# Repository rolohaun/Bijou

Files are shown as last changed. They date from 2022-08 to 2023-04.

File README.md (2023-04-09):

# Bijou

THE ROOK 2020 has replaced this printer!!!!!!!!!

it can be found here
https://www.printables.com/model/447255-rook-2020

Welcome to the DIY 3D Printer called Bijou!

This is a tiny 140x140 H-Bot 3D Printer for beginner builders

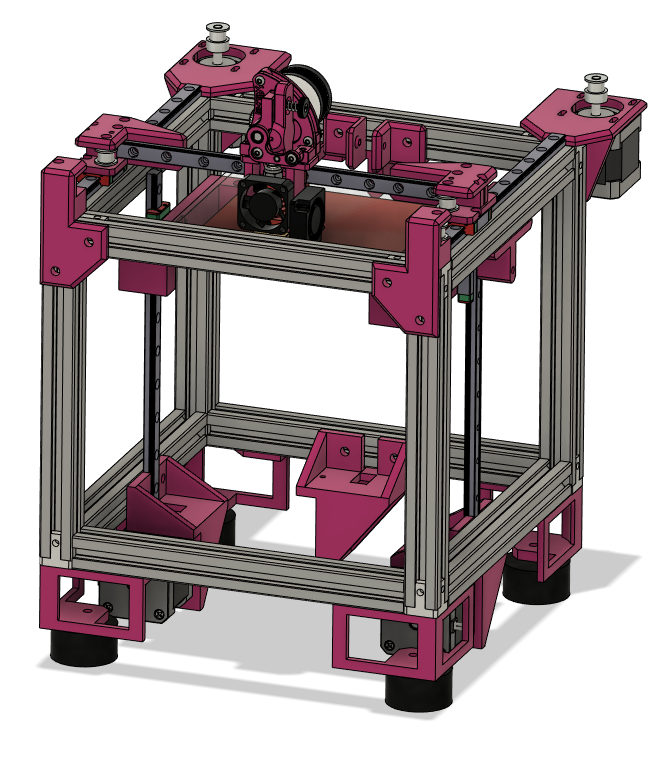
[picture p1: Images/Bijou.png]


PLEASE NOTE THIS PRINTER IS A WORK IN PROGRESS!

The goal of this printer is to make a cheap easy to build 3D printer than can be built by anyone.

Features:

- Simple 2020 Frame only 1 sizes needed, no drilling or taping
- Klicky Probe Support
- Sailfin Direct Drive Extruder Support

BOM Belted Z
https://docs.google.com/spreadsheets/d/1nYMNJQScirm3ykZU8kyfmQuEbCC1vtWDH2YyEYYs_pw/edit?usp=sharing

BOM Lead Screw Z
https://docs.google.com/spreadsheets/d/1incpOYfN3xOxOXJkBM-IeGAFThI5wXblg3JAom1FoRM/edit?usp=sharing

Assembly Videos on Youtube
https://www.youtube.com/watch?v=IN45c1hOG5U&list=PLypdl9fsWkKeVCWAPe8gXl5UOk-Ysh8ol

Support me on Patreon
https://www.patreon.com/rolohaun

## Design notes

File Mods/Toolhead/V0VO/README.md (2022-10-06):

the original V0 toolhead mod V0VO was made by Mamsih I just edited the dragon mount for Bijou. All credit goes to Mamsih for the original
https://github.com/Mamsih/VOV0-toolhead-voron-Zero

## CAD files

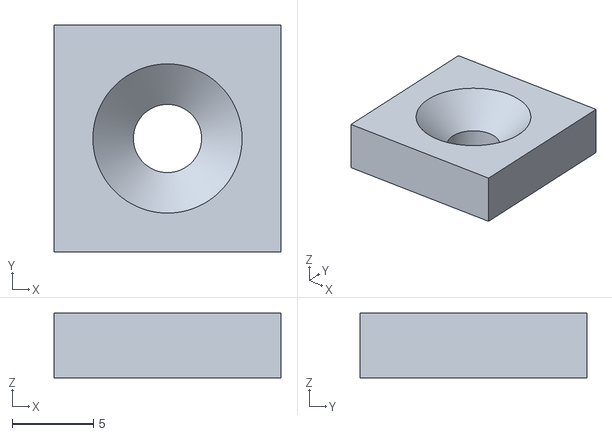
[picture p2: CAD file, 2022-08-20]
Bed/Bed_Pad.stl
14.0 x 14.0 x 4.00

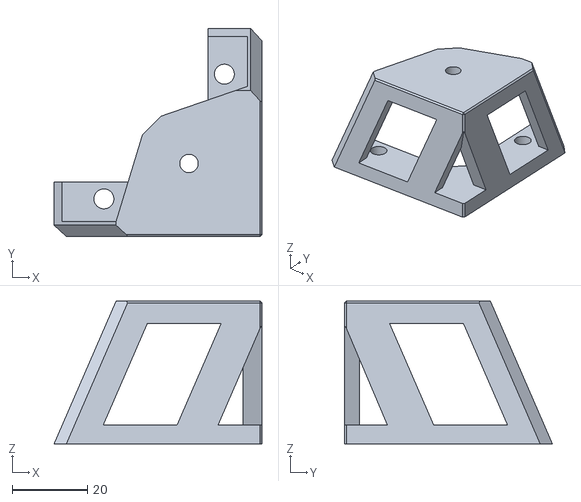
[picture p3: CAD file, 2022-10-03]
Frame + Motor Mounts/Foot_Mount.stl
55.3 x 55.3 x 38.0

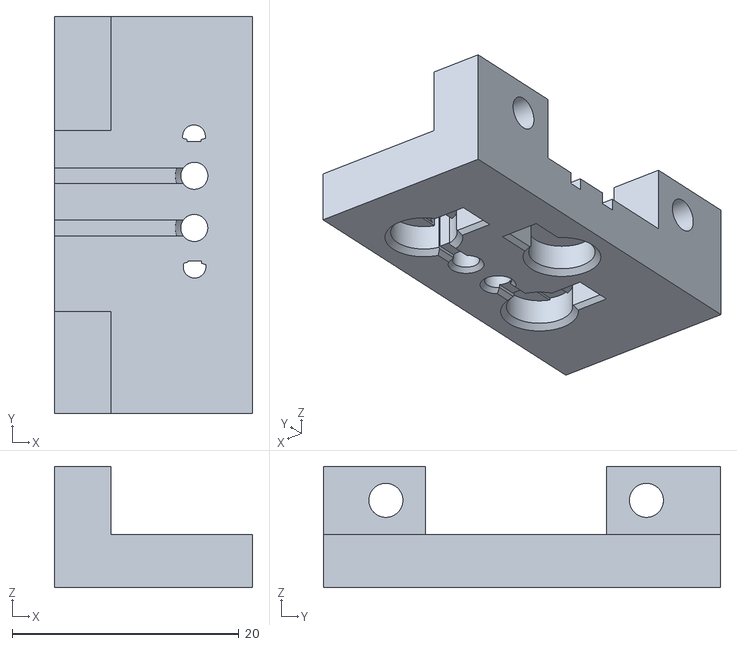
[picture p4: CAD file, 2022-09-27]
Klicky/Bijou_Probe_Mount.stl
17.5 x 35.0 x 10.7

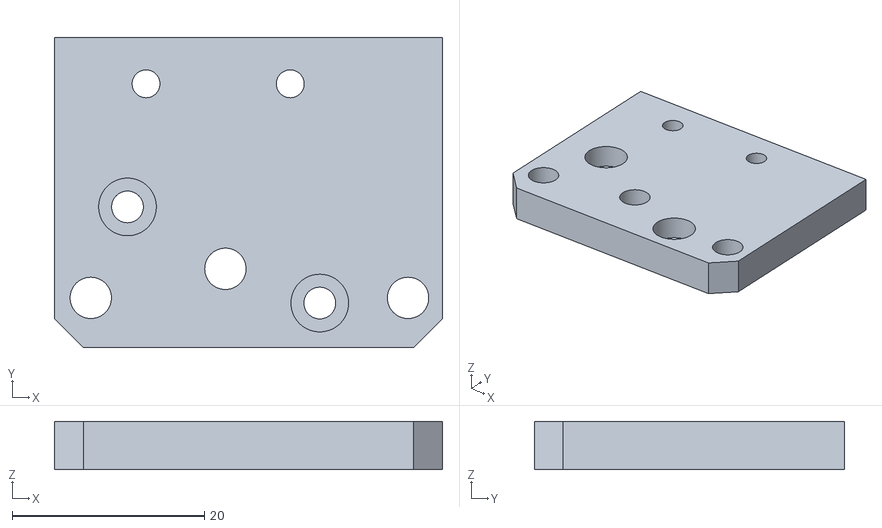
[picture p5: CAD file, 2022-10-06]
Mods/Toolhead/V0VO/V0VO_Sailfin_Adapter.stl
40.4 x 32.3 x 5.00

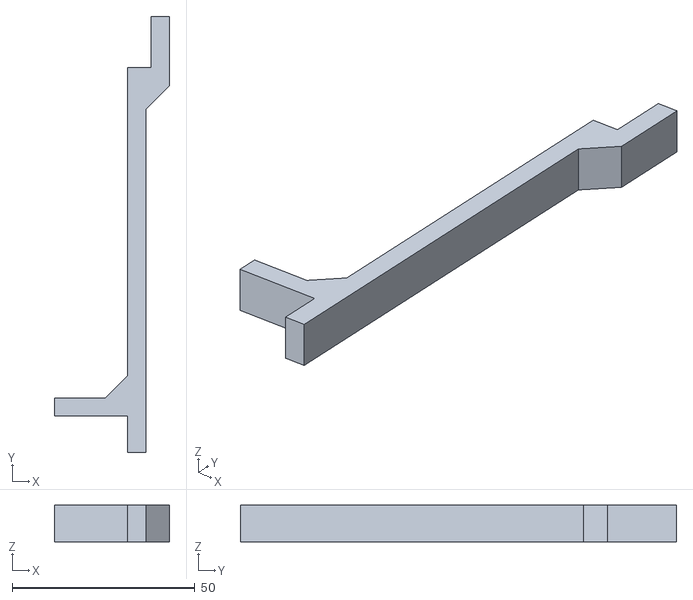
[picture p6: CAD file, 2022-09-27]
Tools/Linear_Rail_Aligment_Tool.stl
31.5 x 119.5 x 10.0

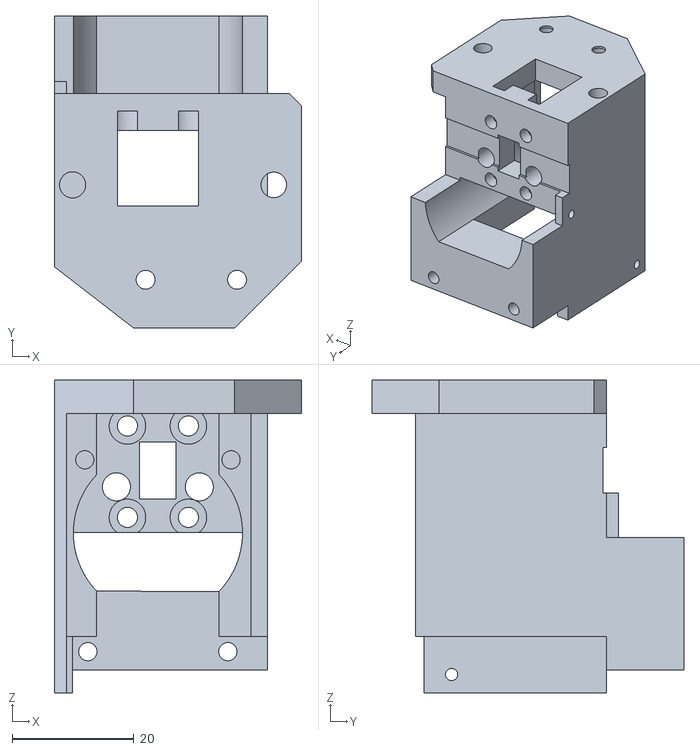
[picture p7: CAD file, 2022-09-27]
X/X_Carriage.stl
40.6 x 51.2 x 51.3

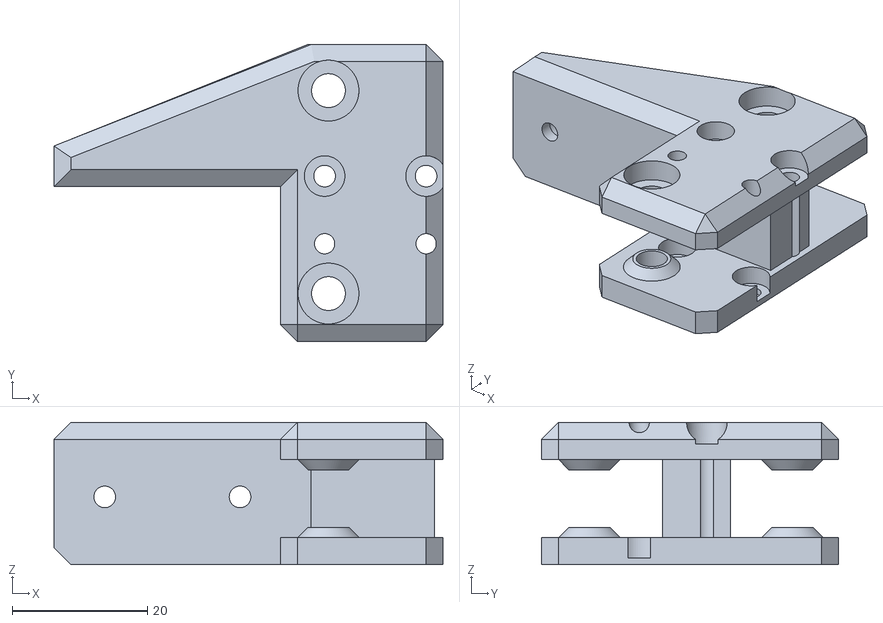
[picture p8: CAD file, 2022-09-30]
Y/Y_Right_M5.stl
57.5 x 43.9 x 21.0

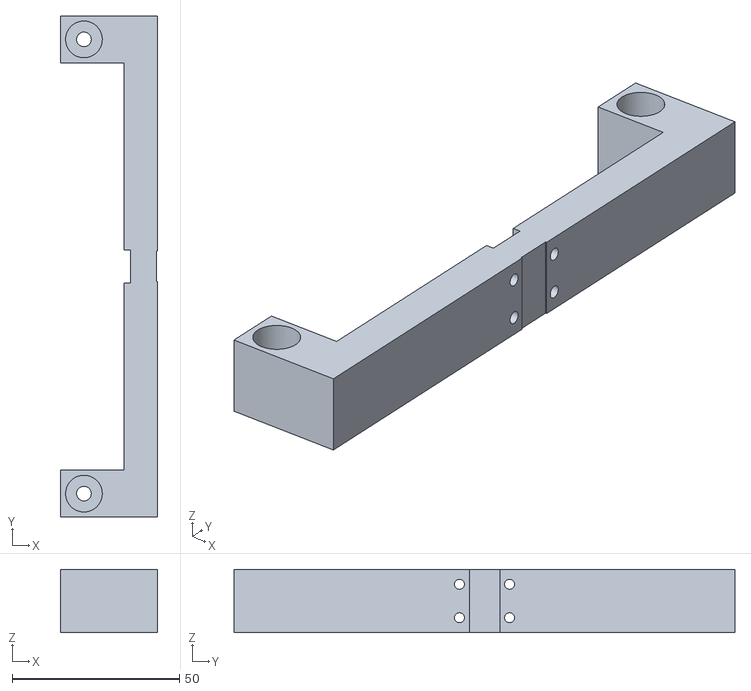
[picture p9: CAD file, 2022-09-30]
Z Belted/Right_Bed_Mount.stl
29.0 x 150.0 x 18.9

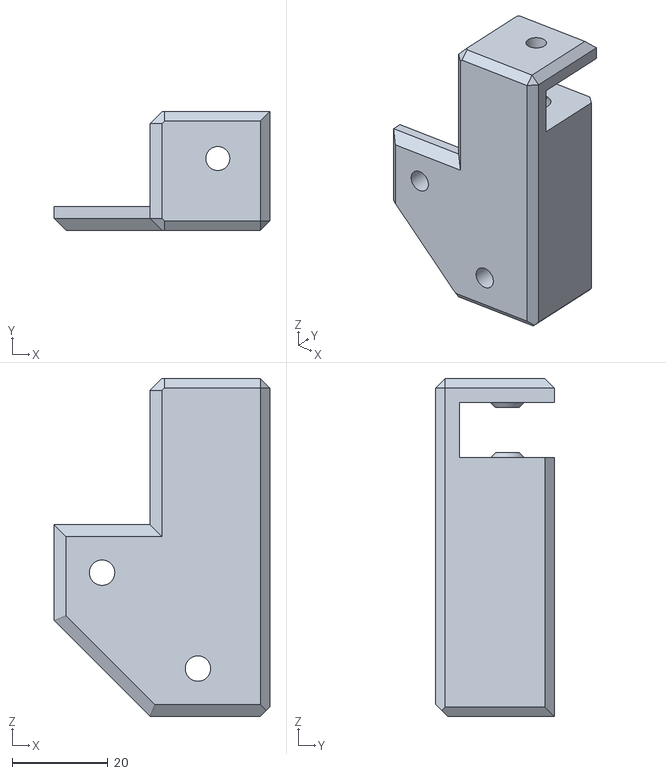
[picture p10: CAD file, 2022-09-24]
Frame + Motor Mounts/Right_Idler_Mount_M5.stl
45.0 x 24.8 x 70.5

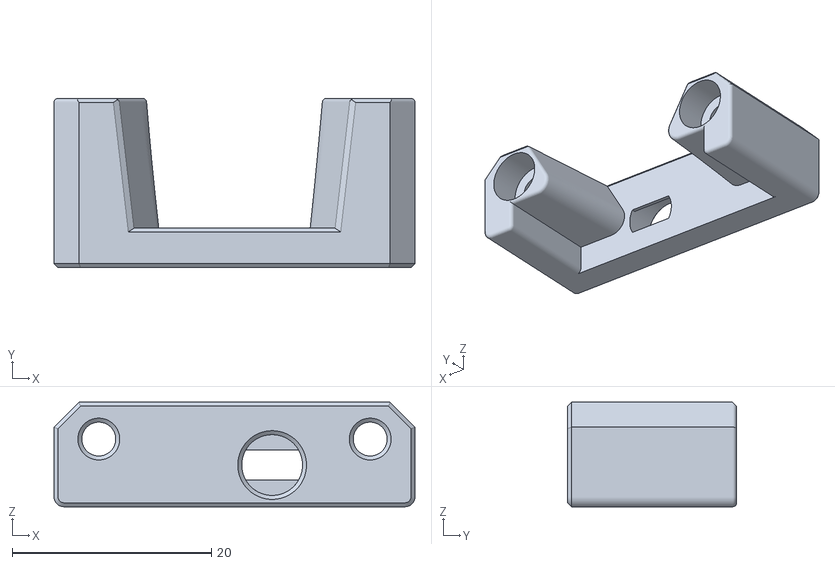
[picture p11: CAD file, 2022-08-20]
Klicky/Probe Dock v2.1.stl
36.3 x 17.0 x 10.5

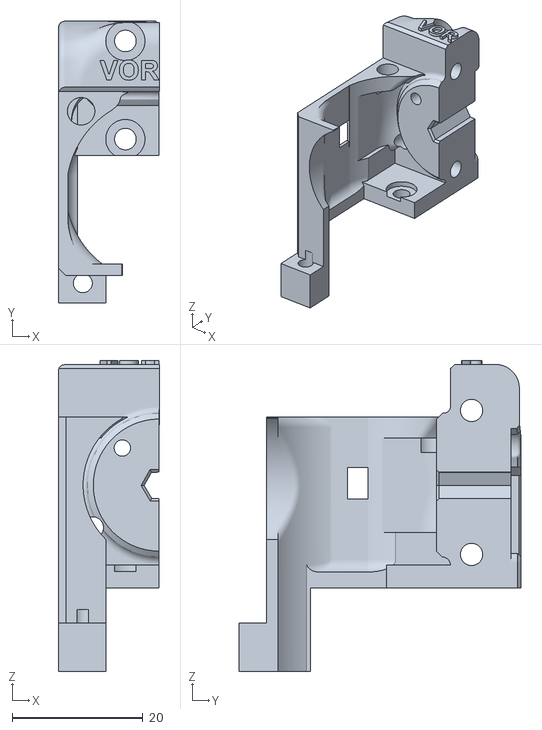
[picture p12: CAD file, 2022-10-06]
Mods/Toolhead/V0VO/hotend-mount_left_dragon.stl
15.4 x 43.1 x 47.5

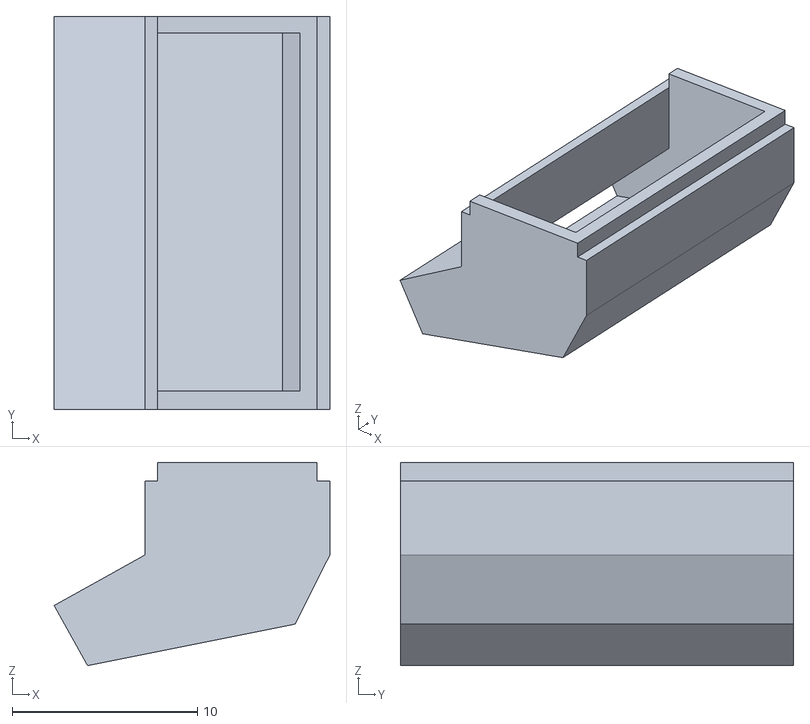
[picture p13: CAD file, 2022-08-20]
X/3010_Fan_Duct.stl
14.9 x 21.2 x 11.0

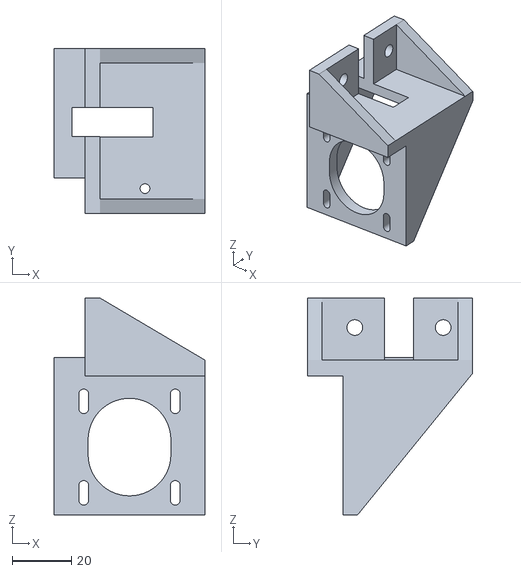
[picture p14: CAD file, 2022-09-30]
Z Belted/Left_Z_Motor_Mount.stl
51.0 x 56.0 x 73.5

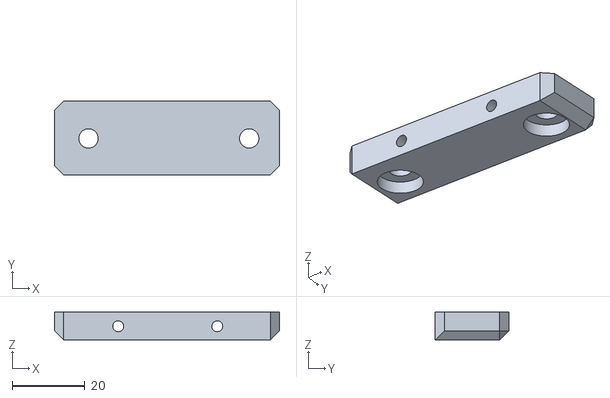
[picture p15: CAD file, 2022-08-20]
Klicky/Frame_Probe_Dock.stl
61.9 x 20.3 x 7.69

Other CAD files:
Y/Y_Left_M5.stl
Frame + Motor Mounts/Left_Idler_Mount_M5.stl
Mods/Toolhead/V0VO/hotend-mount_Right_dragon.stl
Y/Y_Right_M3.stl
Frame + Motor Mounts/Guide_Tube_Mount.stl
Frame + Motor Mounts/Left_Idler_Mount_M3.stl
Frame + Motor Mounts/Left_Motor_Mount.stl
Frame + Motor Mounts/Right_Idler_Mount_M3.stl
Frame + Motor Mounts/Right_Motor_Mount.stl
Klicky/KlickyProbe_v2.stl
Y/Y_Left_M3.stl
Z Belted/2 X Z_Idler_Mount.stl
Z Belted/Left_Bed_Mount.stl
Z Belted/Right_Z_Motor_Mount.stl
Z Lead Screw/2 X LS_Z_Rail_Mount.stl
Z Lead Screw/LS_Z_Bed_Front.stl
Z Lead Screw/LS_Z_Bed_Rear_Left.stl
Z Lead Screw/LS_Z_Bed_Rear_Right.stl
Z Lead Screw/LS_Z_Motor_Mount.stl

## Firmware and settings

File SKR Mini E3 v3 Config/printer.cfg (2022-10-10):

[include mainsail.cfg]
#[include adxl.cfg]
[include klicky-probe.cfg]

[gcode_arcs]
resolution: 1.0

# This file contains common pin mappings for the BIGTREETECH SKR mini
# E3 v3.0. To use this config, the firmware should be compiled for the
# STM32G0B1 with a "8KiB bootloader" and USB communication.

# The "make flash" command does not work on the SKR mini E3. Instead,
# after running "make", copy the generated "out/klipper.bin" file to a
# file named "firmware.bin" on an SD card and then restart the SKR
# mini E3 with that SD card.

# See docs/Config_Reference.md for a description of parameters.

[stepper_x]
step_pin: PB13
dir_pin: PB12
enable_pin: !PB14
microsteps: 64
rotation_distance: 40
full_steps_per_rotation: 200
endstop_pin: tmc2209_stepper_x:virtual_endstop
homing_retract_dist: 0
position_endstop: 140
position_max: 140
homing_speed: 40

[tmc2209 stepper_x]
uart_pin: PC11
tx_pin: PC10
uart_address: 0
run_current: 0.55
sense_resistor: 0.110
stealthchop_threshold: 0
interpolate: False
diag_pin: ^PC0    # Set to MCU pin connected to TMC DIAG pin
driver_SGTHRS: 95 # 255 is most sensitive value, 0 is least sensitive

[stepper_y]
step_pin: PB10
dir_pin: PB2
enable_pin: !PB11
microsteps: 64
rotation_distance: 40
full_steps_per_rotation: 200
endstop_pin: tmc2209_stepper_y:virtual_endstop
homing_retract_dist: 0
position_endstop: 140
position_max: 140
homing_speed: 40

[tmc2209 stepper_y]
uart_pin: PC11
tx_pin: PC10
uart_address: 2
run_current: 0.55
sense_resistor: 0.110
stealthchop_threshold: 0
interpolate: False
diag_pin: ^PC1    # Set to MCU pin connected to TMC DIAG pin
driver_SGTHRS: 90  # 255 is most sensitive value, 0 is least sensitive

[stepper_z]
step_pin: PB0
dir_pin: !PC5
enable_pin: !PB1
microsteps: 64
rotation_distance: 8
endstop_pin: probe:z_virtual_endstop
position_min: -10
position_max: 120
homing_speed: 40

[tmc2209 stepper_z]
uart_pin: PC11
tx_pin: PC10
uart_address: 1
run_current: 0.5
sense_resistor: 0.110
stealthchop_threshold: 0
interpolate: False

[extruder]
step_pin: PB3
dir_pin: !PB4
enable_pin: !PD1
microsteps: 64
rotation_distance: 22.02
gear_ratio: 50:10	
nozzle_diameter: 0.400
filament_diameter: 1.750
heater_pin: PC8
sensor_type: Generic 3950
sensor_pin: PA0
#control: pid
#pid_Kp: 21.527
#pid_Ki: 1.063
#pid_Kd: 108.982
min_temp: 0
min_extrude_temp: 10
max_temp: 250
pressure_advance: 0.04
##	Default is 0.040, leave stock
pressure_advance_smooth_time: 0.040

[tmc2209 extruder]
uart_pin: PC11
tx_pin: PC10
uart_address: 3
run_current: 0.4
sense_resistor: 0.110
stealthchop_threshold: 0
interpolate: False

#[heater_bed]
#heater_pin: PC9
#sensor_type: ATC Semitec 104GT-2
#sensor_pin: PC4
#control: pid
#pid_Kp: 54.027
#pid_Ki: 0.770
#pid_Kd: 948.182
#min_temp: 0
#max_temp: 130

[probe]
##	If your probe is NO instead of NC, change pin to ^!PA3
pin: ^PC2
x_offset: 0
y_offset: 20
z_offset: 2
speed: 5
samples: 3
samples_result: median
sample_retract_dist: 3.0
samples_tolerance: 0.05
samples_tolerance_retries: 3

#[safe_z_home]
#home_xy_position: 75, 73 # Change coordinates to the center of your print bed
#speed: 40
#z_hop: 0                 # Move up 10mm
#z_hop_speed: 5

[heater_fan nozzle_cooling_fan]
pin: PC7

[heater_fan controller_fan]
pin: PB15

[fan]
pin: PC6

[mcu]
serial: /dev/serial/by-id/usb-Klipper_stm32g0b1xx_2F0014000550415339373620-if00

[printer]
kinematics: corexy
max_velocity: 300
max_accel: 2000
max_z_velocity: 10
max_z_accel: 100

[board_pins]
aliases:
    # EXP1 header
    EXP1_1=PB5,  EXP1_3=PA9,   EXP1_5=PA10, EXP1_7=PB8, EXP1_9=<GND>,
    EXP1_2=PA15, EXP1_4=<RST>, EXP1_6=PB9,  EXP1_8=PD6, EXP1_10=<5V>

# See the sample-lcd.cfg file for definitions of common LCD displays.

#*# <---------------------- SAVE_CONFIG ---------------------->
#*# DO NOT EDIT THIS BLOCK OR BELOW. The contents are auto-generated.
#*#
#*# [extruder]
#*# control = pid
#*# pid_kp = 25.292
#*# pid_ki = 1.328
#*# pid_kd = 120.454
#*#
#*# [input_shaper]
#*# shaper_type_x = 2hump_ei
#*# shaper_freq_x = 81.0
#*# shaper_type_y = zv
#*# shaper_freq_y = 78.8

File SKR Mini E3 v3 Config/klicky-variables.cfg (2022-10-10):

# This macro was provided by discord user Garrettwp to whom i give my thanks for sharing it with me.
# I have tweaked it a lot.
# They are based on the great Annex magprobe dockable probe macros "#Originally developed by Mental,
# modified for better use on K-series printers by RyanG and Trails", kudos to them.
# That macro as since evolved into a klipper plugin that currently is pending inclusion in klipper, 
# more information here, https://github.com/Annex-Engineering/Quickdraw_Probe/tree/main/Klipper_Macros
# User richardjm revised the macro variables and added some functions, thanks a lot
# by standing on the shoulders of giants, lets see if we can see further
#
# the current home for this version is https://github.com/jlas1/Klicky-Probe 
# the 1000 values below is to give an error instead of doing something wrong, hopefully, this won't be used is a printer larger than 1 meter

[gcode_macro _User_Variables]
variable_verbose:             True    # Enable verbose output
variable_travel_speed:         150    # how fast all other travel moves will be performed when running these macros
variable_move_accel:          1000    # how fast should the toolhead accelerate when moving
variable_dock_speed:            50    # how fast should the toolhead move when docking the probe for the final movement
variable_release_speed:         75    # how fast should the toolhead move to release the hold of the magnets after docking
variable_z_drop_speed:          20    # how fast the z will lower when moving to the z location to clear the probe

variable_safe_z:         	    10    # Minimum Z for attach/dock and homing functions
# if true it will move the bed away from the nozzle when Z is not homed
variable_enable_z_hop:        False    # set this to false for beds that fall significantly under gravity (almost to Z max)

variable_max_bed_x:            165    # maximum Bed size avoids doing a probe_accuracy outside the bed
variable_max_bed_y:            165    # maximum Bed size avoids doing a probe_accuracy outside the bed


# if a separate Z endstop switch is in
# use, specify the coordinates of the switch here (Voron).
# Set to 0 to have the probe move to center of bed
variable_z_endstop_x:         0 #changed
variable_z_endstop_y:         0 #changed

#Check the printer specific documentation on klipper Dock/Undock configuration, these are dummy values
#dock location 
variable_docklocation_x:      25    # X Dock position
variable_docklocation_y:      139   # Y Dock position
variable_docklocation_z:      -128    # Z dock position (-128 for a gantry/frame mount)

#Dock move, final toolhead movement to release the probe on the dock
#it's a relative move
Variable_dockmove_x:             40
Variable_dockmove_y:             0
Variable_dockmove_z:             0
#Attach move. final toolhead movement to attach the probe on the mount
#it's a relative move
Variable_attachmove_x:           0
Variable_attachmove_y:           30
Variable_attachmove_z:           0

#Umbilical to help untangle the umbilical in difficult situations
variable_umbilical:          False    # should we untabgle the umbilical
variable_umbilical_x:           15    # X umbilical position
variable_umbilical_y:           15    # Y umbilical position

# location to park the toolhead
variable_park_toolhead:      False    # Enable toolhead parking
variable_parkposition_x:       125
variable_parkposition_y:       125
variable_parkposition_z:        30

variable_version:                1    # Helps users to update the necessary variables, do not update if the variables above are not updated

#Below this remark, you normally do not need to configure
#Attach move2
Variable_attachmove2_x:          0    # intermediate toolhead movement to attach
Variable_attachmove2_y:          0    # the probe on the dock
Variable_attachmove2_z:          0    # (can be negative)

# Do not modify below
gcode:
    {% set Mx = printer['configfile'].config["stepper_x"]["position_max"]|float %}
    {% set My = printer['configfile'].config["stepper_y"]["position_max"]|float %}
    {% set Ox = printer['configfile'].config["probe"]["x_offset"]|float %}
    {% set Oy = printer['configfile'].config["probe"]["y_offset"]|float %}
    {% set Oz = printer['configfile'].config["probe"]["z_offset"]|float %}

    # If x, y coordinates are set for z endstop, assign them
    {% if z_endstop_x != 0 or z_endstop_y != 0 %}
        SET_GCODE_VARIABLE MACRO=_Probe_Variables VARIABLE=z_endstop_x VALUE={ z_endstop_x }
        SET_GCODE_VARIABLE MACRO=_Probe_Variables VARIABLE=z_endstop_y VALUE={ z_endstop_y }

    # if no x, y coordinates for z endstop, assume probe is endstop and move toolhead to center of bed
    {% else %}
        SET_GCODE_VARIABLE MACRO=_Probe_Variables VARIABLE=z_endstop_x VALUE={ (Mx * 0.5) - Ox }
        SET_GCODE_VARIABLE MACRO=_Probe_Variables VARIABLE=z_endstop_y VALUE={ (My * 0.5) - Oy }
    {% endif %}

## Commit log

2022-08-20 V1 Release
    [3010_Fan_Duct.stl, Bed_Mount.stl, Right_Bed_Mount.stl]
2022-08-24 Minor Revisions
    [Bijou_Probe_Mount.stl, X_Bijou_Probe_Mount_addon.stl, X_Carriage.stl]
2022-09-25 Added M3 and M5 versions
    [Left_Idler_Mount_M3.stl, Right_Idler_Mount_M3.stl, Y_Left_M3.stl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]
2022-09-27 remnoved lead screw Z
    [2 X LS_Z_Rail_Mount.stl, LS_Left_Bed_Mount.stl, LS_Right_Bed_Mount.stl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]
2022-09-28 MK1 Update
    [2 X Z_Idler_Mount.stl, Left_Z_Motor_Mount.stl, Right_Z_Motor_Mount.stl]
2022-10-10 SKR config MK1
    [adxl.cfg, klicky-macros.cfg, klicky-probe.cfg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]
2022-10-26 Removed old Klicky stuff
    [X_Bijou_Probe_Mount_addon.stl, X_CarriageKlicky_adapter.stl]
